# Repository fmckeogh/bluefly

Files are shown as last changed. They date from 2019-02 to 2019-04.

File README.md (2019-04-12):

# bluefly

> BLE-based light electric vehicle control system




## Building

TODO

## Components

* nRF52810 microcontrollers
* SSD1306 display
* NCR18650GA battery
* Hall-effect thumb control

## TODO

### Software

* [ ] MVP (move thumb and motor spins as a result)
* [ ] Proper BLE connection
* [ ] Display telemetry
* [ ] Transparent passthrough to VESC for configuration from PC/phone
* [ ] CLI for configuring remote/receiver
* [ ] OTA firmware updates of remote and receiver
* [ ] Battery percent on phone
* [ ] HomeKit integration

### Hardware

* [X] Finalise breadboard design of both remote and receiver
* [x] Initial PCB design and order of both remote and receiver
* [ ] Case design

## Contributing

Issues and PRs very welcome :)

## License

Mozilla Public License Version 2.0([LICENSE](LICENSE) or
  https://www.mozilla.org/en-US/MPL/2.0/)

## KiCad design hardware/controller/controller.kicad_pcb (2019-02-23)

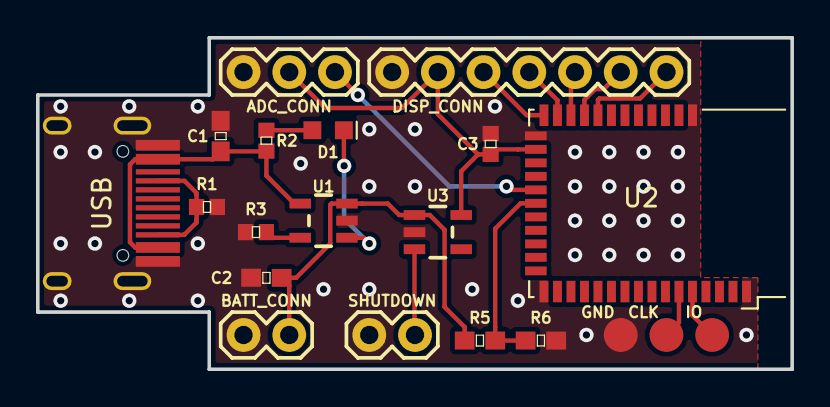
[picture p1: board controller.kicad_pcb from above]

Board: 2 copper layers, 41.9 x 18.4 mm, 20 parts (0 on the bottom side), 18 nets.

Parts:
C1, C2: 4.7UF; 0603
C3: 1.0UF-0402-16V-10%; 0402
D1: LED-BLUE0603; LED-0603
J1: ADC_CONN; 1X03
J2: DISP_CONN; 1X07
J3: BATT_CONN; 1X02
J4: SHUTDOWN; 1X02
R1: 5.1K; 0402
R2: RESISTOR0402; 0402
R3: 2K; 0402
R5, R6: 1MOHM-0603-1_4W-5%; 0603
SWD_CLK1: CLK; PAD.03X.05
SWD_GND1: GND; PAD.03X.05
SWD_IO1: IO; PAD.03X.05
U1: MCP73831; SOT23-5
U2: BL652; Laird_BL652
U3: TC1014; SOT23-5
USB: HRO-TYPE-C-31-M-12; HRO-TYPE-C-31-M-12-HandSoldering_modified

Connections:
/AIN0: J1.3, U2.23
/AIN1: R5.2, R6.1, U2.22
/CC: R1.1, USB.4, USB.10
/CS: J2.7, U2.32
/DC: J2.5, U2.30
/MOSI: J2.3, U2.28
/RST: J2.6, U2.31
/SCK: J2.4, U2.29
/SWDCLK: SWD_CLK1.P$1, U2.6
/SWDIO: SWD_IO1.P$1, U2.5
GND: C1.2, C2.2, C3.2, J1.1, J2.1, J3.1, J4.2, R1.2, R3.2, R6.2, SWD_GND1.P$1, U1.2, U2.1, U2.16, U2.27, U2.39, U3.2, USB.1, USB.12, USB.13
unnamed: D1.A, R2.1
unnamed: D1.C, U1.1
unnamed: J4.1, U3.3
unnamed: R3.1, U1.5
VCC: C3.1, J1.2, J2.2, U2.26, U3.5
V_BATT: C2.1, J3.2, R5.1, U1.3, U3.1
V_USB: C1.1, R2.2, U1.4, USB.2, USB.11

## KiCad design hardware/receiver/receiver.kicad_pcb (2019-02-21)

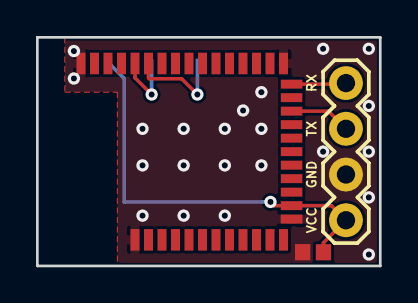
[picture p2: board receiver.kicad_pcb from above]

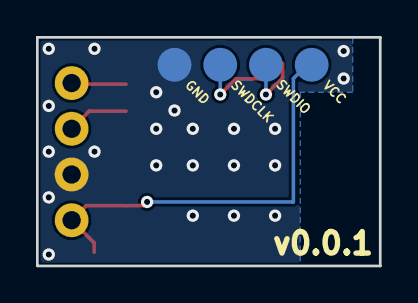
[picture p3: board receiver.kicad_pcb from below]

Board: 2 copper layers, 19.0 x 12.7 mm, 5 parts (4 on the bottom side), 2 nets.

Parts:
C1: 0.1UF-0402-16V-10%; 0402_mod
GND1: TEST-POINT3; PAD.03X.05
SWDCLK1: TEST-POINT3; PAD.03X.05
SWDIO1: TEST-POINT3; PAD.03X.05
VCC1: TEST-POINT3; PAD.03X.05

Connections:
GND: C1.2, GND1.P$1
VCC: C1.1, VCC1.P$1

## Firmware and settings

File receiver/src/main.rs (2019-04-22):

#![no_std]
#![no_main]

// We need to import this crate explicitly so we have a panic handler
extern crate panic_semihosting;

mod logger;
mod radio;
mod timer;

use {
    crate::logger::{BbqLogger, StampedLogger},
    crate::{
        radio::{BleRadio, PacketBuffer},
        timer::{BleTimer, StampSource},
    },
    bbqueue::{bbq, BBQueue, Consumer},
    core::fmt::Write,
    log::{info, LevelFilter},
    nrf52810_hal::{
        self as hal,
        gpio::Level,
        nrf52810_pac::{self as pac, UARTE0},
        prelude::*,
        uarte::{Baudrate, Parity, Uarte},
    },
    rtfm::app,
    rubble::{
        beacon::{BeaconScanner, ScanCallback},
        gatt::GattServer,
        l2cap::{BleChannelMap, L2CAPState},
        link::{
            ad_structure::AdStructure, filter::WhitelistFilter, queue, AddressKind, DeviceAddress,
            HardwareInterface, LinkLayer, Responder, MAX_PDU_SIZE,
        },
        security_manager::NoSecurity,
        time::{Duration, Timer},
    },
};

type Logger = StampedLogger<StampSource<pac::TIMER0>, BbqLogger>;

/// Hardware interface for the BLE stack (nRF52810 implementation).
pub struct HwNRf52810 {}

impl HardwareInterface for HwNRf52810 {
    type Timer = BleTimer<pac::TIMER0>;
    type Tx = BleRadio;
}

/// Whether to broadcast a beacon or to establish a proper connection.
///
/// This is just used to test different code paths. Note that you can't do both
/// at the same time unless you also generate separate device addresses.
const TEST_BEACON: bool = false;

/// Stores the global logger used by the `log` crate.
static mut LOGGER: Option<logger::WriteLogger<Logger>> = None;

#[app(device = nrf52810_hal::nrf52810_pac)]
const APP: () = {
    static mut BLE_TX_BUF: PacketBuffer = [0; MAX_PDU_SIZE];
    static mut BLE_RX_BUF: PacketBuffer = [0; MAX_PDU_SIZE];
    static mut BLE_LL: LinkLayer<HwNRf52810> = ();
    static mut BLE_R: Responder<BleChannelMap<GattServer<'static>, NoSecurity>> = ();
    static mut RADIO: BleRadio = ();
    static mut SCANNER: rubble::beacon::BeaconScanner<
        PwmCallback,
        rubble::link::filter::WhitelistFilter<core::iter::Once<rubble::link::DeviceAddress>>,
    > = ();
    static mut SERIAL: Uarte<UARTE0> = ();
    static mut LOG_SINK: Consumer = ();

    #[init(resources = [BLE_TX_BUF, BLE_RX_BUF])]
    fn init() {
        {
            // On reset the internal high frequency clock is used, but starting the HFCLK task
            // switches to the external crystal; this is needed for Bluetooth to work.

            device
                .CLOCK
                .tasks_hfclkstart
                .write(|w| unsafe { w.bits(1) });
            while device.CLOCK.events_hfclkstarted.read().bits() == 0 {}
        }

        let ble_timer = BleTimer::init(device.TIMER0);

        let p0 = device.P0.split();

        let mut serial = {
            let rxd = p0.p0_08.into_floating_input().degrade();
            let txd = p0.p0_06.into_push_pull_output(Level::Low).degrade();

            let pins = hal::uarte::Pins {
                rxd,
                txd,
                cts: None,
                rts: None,
            };

            device
                .UARTE0
                .constrain(pins, Parity::EXCLUDED, Baudrate::BAUD1M)
        };
        writeln!(serial, "\n--- INIT ---").unwrap();

        let device_address = DeviceAddress::new([0, 0, 0, 0, 0, 0], AddressKind::Random);

        let mut radio = BleRadio::new(device.RADIO, resources.BLE_TX_BUF, resources.BLE_RX_BUF);

        let log_stamper = ble_timer.create_stamp_source();
        let (tx, log_sink) = bbq![10000].unwrap().split();
        let logger = StampedLogger::new(BbqLogger::new(tx), log_stamper);

        let log = logger::WriteLogger::new(logger);
        // Safe, since we're the only thread and interrupts are off
        unsafe {
            LOGGER = Some(log);
            log::set_logger(LOGGER.as_ref().unwrap()).unwrap();
        }
        log::set_max_level(LevelFilter::max());

        info!("READY");

        // Create TX/RX queues
        let (tx, tx_cons) = queue::create(bbq![1024].unwrap());
        let (rx_prod, rx) = queue::create(bbq![1024].unwrap());

        // Create the actual BLE stack objects
        let mut ll = LinkLayer::<HwNRf52810>::new(device_address, ble_timer);

        let resp = Responder::new(
            tx,
            rx,
            L2CAPState::new(BleChannelMap::with_attributes(GattServer::new())),
        );

        if !TEST_BEACON {
            // Send advertisement and set up regular interrupt
            let next_update = ll
                .start_advertise(
                    Duration::from_millis(200),
                    &[AdStructure::CompleteLocalName("CONCVRRENS CERTA CELERIS")],
                    &mut radio,
                    tx_cons,
                    rx_prod,
                )
                .unwrap();
            ll.timer().configure_interrupt(next_update);
        }

        let scanner = {
            let filter = WhitelistFilter::from_address(DeviceAddress::new(
                [169, 255, 235, 206, 50, 121],
                AddressKind::Random,
            ));

            let callback = {
                device.PWM0.psel.out[0]
                    .write(|w| unsafe { w.pin().bits(0x08).connect().connected() });
                device.PWM0.enable.write(|w| w.enable().enabled());
                device.PWM0.mode.write(|w| w.updown().up());
                device.PWM0.prescaler.write(|w| w.prescaler().div_32());
                device
                    .PWM0
                    .countertop
                    .write(|w| unsafe { w.countertop().bits(8_000) }); // 20ms at div_32
                device.PWM0.loop_.write(|w| w.cnt().disabled());
                device
                    .PWM0
                    .decoder
                    .write(|w| w.load().common().mode().next_step());
                device.PWM0.seq0.refresh.write(|w| w.cnt().continuous());
                device
                    .PWM0
                    .seq0
                    .enddelay
                    .write(|w| unsafe { w.cnt().bits(0) });
                let mut val: u16 = 7220;
                device.PWM0.seq0.cnt.write(|w| unsafe { w.cnt().bits(1) });
                device
                    .PWM0
                    .seq0
                    .ptr
                    .write(|w| unsafe { w.ptr().bits(((&mut val) as *mut _) as u32) });

                device.PWM0.tasks_seqstart[0].write(|w| w.tasks_seqstart().trigger());
                device
                    .PWM0
                    .tasks_nextstep
                    .write(|w| w.tasks_nextstep().trigger());

                PwmCallback(device.PWM0)
            };

            BeaconScanner::with_filter(callback, filter)
        };

        RADIO = radio;
        BLE_LL = ll;
        BLE_R = resp;
        SCANNER = scanner;
        SERIAL = serial;
        LOG_SINK = log_sink;
    }

    #[interrupt(resources = [RADIO, BLE_LL, SCANNER])]
    fn RADIO() {
        let next_update = resources
            .RADIO
            .recv_interrupt(resources.BLE_LL.timer().now(), &mut resources.SCANNER);

        //let cmd = resources.SCANNER.process_adv_packet()
        resources.BLE_LL.timer().configure_interrupt(next_update);
    }

    #[interrupt(resources = [RADIO, BLE_LL, SCANNER])]
    fn TIMER0() {
        let timer = resources.BLE_LL.timer();
        if !timer.is_interrupt_pending() {
            return;
        }
        timer.clear_interrupt();

        let cmd = resources.BLE_LL.update(&mut *resources.RADIO);
        resources.RADIO.configure_receiver(cmd.radio);

        resources
            .BLE_LL
            .timer()
            .configure_interrupt(cmd.next_update);
    }

    #[idle(resources = [LOG_SINK, SERIAL, BLE_R])]
    fn idle() -> ! {
        // Drain the logging buffer through the serial connection
        loop {
            while let Ok(grant) = resources.LOG_SINK.read() {
                for chunk in grant.buf().chunks(255) {
                    resources.SERIAL.write(chunk).unwrap();
                }

                resources.LOG_SINK.release(grant.buf().len(), grant);
            }

            if resources.BLE_R.has_work() {
                resources.BLE_R.process_one().unwrap();
            }
        }
    }
};

pub struct PwmCallback(pac::PWM0);

impl ScanCallback for PwmCallback {
    fn beacon<'a, I>(&mut self, _adv_addr: DeviceAddress, adv_data: I)
    where
        I: Iterator<Item = AdStructure<'a>>,
    {
        match adv_data.last() {
            Some(AdStructure::Unknown { ty: _, data }) => {
                info!("got val: {}", data[0]);

                let mut val: u16 = 6990 + (u16::from(data[0]) * 2);
                self.0.seq0.cnt.write(|w| unsafe { w.cnt().bits(1) });
                self.0
                    .seq0
                    .ptr
                    .write(|w| unsafe { w.ptr().bits(((&mut val) as *mut _) as u32) });

                self.0.tasks_seqstart[0].write(|w| w.tasks_seqstart().trigger());
                self.0
                    .tasks_nextstep
                    .write(|w| w.tasks_nextstep().trigger());
            }
            _ => (),
        }
    }
}

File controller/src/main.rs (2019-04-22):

#![no_std]
#![no_main]
#![feature(alloc)]
#![feature(global_allocator)]
#![feature(lang_items)]

// We need to import this crate explicitly so we have a panic handler
#[macro_use]
extern crate alloc;
extern crate alloc_cortex_m;
extern crate panic_semihosting;
#[macro_use]
extern crate cortex_m_rt as rt;

mod logger;

use {
    crate::logger::{BbqLogger, StampedLogger},
    alloc_cortex_m::CortexMHeap,
    bbqueue::{bbq, BBQueue, Consumer},
    core::alloc::Layout,
    core::fmt::Write,
    embedded_graphics::{fonts::Font12x16, image::Image1BPP, prelude::*},
    embedded_hal::adc::OneShot,
    log::{info, LevelFilter},
    nrf52810_hal::{
        self as hal,
        gpio::{
            p0::{P0_02, P0_03},
            Floating, Input, Level, Output, Pin, PushPull,
        },
        nrf52810_pac::{self as pac, SPIM0, UARTE0},
        prelude::*,
        saadc::{Gain, Oversample, Reference, Resistor, Resolution, Saadc, SaadcConfig, Time},
        spim::{self, Frequency, Spim, MODE_0},
        uarte::{Baudrate, Parity, Uarte},
    },
    rtfm::app,
    rubble::{
        beacon::Beacon,
        gatt::GattServer,
        l2cap::{BleChannelMap, L2CAPState},
        link::{
            ad_structure::AdStructure, queue, AddressKind, DeviceAddress, HardwareInterface,
            LinkLayer, Responder, MAX_PDU_SIZE,
        },
        security_manager::NoSecurity,
        time::Timer,
    },
    rubble_nrf52810::{
        radio::{BleRadio, PacketBuffer},
        timer::{BleTimer, StampSource},
    },
    ssd1306::{
        displayrotation::DisplayRotation, interface::spi::SpiInterface,
        mode::graphics::GraphicsMode, prelude::*,
    },
};

#[global_allocator]
static ALLOCATOR: CortexMHeap = CortexMHeap::empty();

type Logger = StampedLogger<StampSource<pac::TIMER0>, BbqLogger>;

/// Hardware interface for the BLE stack (nRF52810 implementation).
pub struct HwNRf52810 {}

impl HardwareInterface for HwNRf52810 {
    type Timer = BleTimer<pac::TIMER0>;
    type Tx = BleRadio;
}

/// Stores the global logger used by the `log` crate.
static mut LOGGER: Option<logger::WriteLogger<Logger>> = None;

#[app(device = nrf52810_hal::nrf52810_pac)]
const APP: () = {
    static mut BLE_TX_BUF: PacketBuffer = [0; MAX_PDU_SIZE];
    static mut BLE_RX_BUF: PacketBuffer = [0; MAX_PDU_SIZE];
    static mut BLE_LL: LinkLayer<HwNRf52810> = ();
    static mut BLE_R: Responder<BleChannelMap<GattServer<'static>, NoSecurity>> = ();
    static mut RADIO: BleRadio = ();
    static mut BEACON_TIMER: pac::TIMER1 = ();
    static mut SERIAL: Uarte<UARTE0> = ();
    static mut LOG_SINK: Consumer = ();

    static mut DISPLAY: GraphicsMode<SpiInterface<Spim<SPIM0>, Pin<Output<PushPull>>>> = ();

    static mut ADC: Saadc = ();
    static mut ADC_CONTROL_PIN: P0_02<Input<Floating>> = ();
    static mut ADC_BATT_PIN: P0_03<Input<Floating>> = ();

    #[init(resources = [BLE_TX_BUF, BLE_RX_BUF])]
    fn init() {
        //hprintln!("\n<< INIT >>\n").ok();
        {
            let start = rt::heap_start() as usize;
            let size = 1024; // in bytes
            unsafe { ALLOCATOR.init(start, size) }
        }

        {
            // On reset the internal high frequency clock is used, but starting the HFCLK task
            // switches to the external crystal; this is needed for Bluetooth to work.

            device
                .CLOCK
                .tasks_hfclkstart
                .write(|w| unsafe { w.bits(1) });
            while device.CLOCK.events_hfclkstarted.read().bits() == 0 {}
        }

        let ble_timer = BleTimer::init(device.TIMER0);

        {
            // Configure TIMER1 as the beacon timer. It's only used as a 16-bit timer.
            let timer = &mut device.TIMER1;
            timer.bitmode.write(|w| w.bitmode()._16bit());
            // prescaler = 2^9    = 512
            // 16 MHz / prescaler = 31_250 Hz
            timer.prescaler.write(|w| unsafe { w.prescaler().bits(9) }); // 0-9
            timer.intenset.write(|w| w.compare0().set());
            timer.shorts.write(|w| w.compare0_clear().enabled());
            timer.cc[0].write(|w| unsafe { w.bits(31_250 / 50) }); // ~50x per second
            timer.tasks_clear.write(|w| unsafe { w.bits(1) });

            timer.tasks_start.write(|w| unsafe { w.bits(1) });
        }

        let p0 = device.P0.split();

        let mut serial = {
            let rxd = p0.p0_08.into_floating_input().degrade();
            let txd = p0.p0_31.into_push_pull_output(Level::Low).degrade();

            let pins = hal::uarte::Pins {
                rxd,
                txd,
                cts: None,
                rts: None,
            };

            device
                .UARTE0
                .constrain(pins, Parity::EXCLUDED, Baudrate::BAUD1M)
        };
        writeln!(serial, "\n--- INIT ---").unwrap();

        let radio = BleRadio::new(device.RADIO, resources.BLE_TX_BUF, resources.BLE_RX_BUF);

        let log_stamper = ble_timer.create_stamp_source();
        let (tx, log_sink) = bbq![10000].unwrap().split();
        let logger = StampedLogger::new(BbqLogger::new(tx), log_stamper);

        let log = logger::WriteLogger::new(logger);
        // Safe, since we're the only thread and interrupts are off
        unsafe {
            LOGGER = Some(log);
            log::set_logger(LOGGER.as_ref().unwrap()).unwrap();
        }
        log::set_max_level(LevelFilter::max());

        info!("READY");

        // Create TX/RX queues
        let (tx, _tx_cons) = queue::create(bbq![1024].unwrap());
        let (_rx_prod, rx) = queue::create(bbq![1024].unwrap());

        // Create the actual BLE stack objects
        let ll = LinkLayer::<HwNRf52810>::new(
            DeviceAddress::new([169, 255, 235, 206, 50, 121], AddressKind::Random),
            ble_timer,
        );

        let resp = Responder::new(
            tx,
            rx,
            L2CAPState::new(BleChannelMap::with_attributes(GattServer::new())),
        );

        let adc = {
            let config = SaadcConfig {
                resolution: Resolution::_14BIT,
                oversample: Oversample::OVER256X,
                reference: Reference::VDD1_4,
                gain: Gain::GAIN1_4,
                resistor: Resistor::BYPASS,
                time: Time::_40US,
            };

            Saadc::new(device.SAADC, config)
        };

        let display = {
            let spi = {
                let mosi = Some(p0.p0_15.into_push_pull_output(Level::Low).degrade());
                let sck = p0.p0_13.into_push_pull_output(Level::Low).degrade();

                Spim::new(
                    device.SPIM0,
                    spim::Pins {
                        sck,
                        mosi,
                        miso: None,
                    },
                    Frequency::M8,
                    MODE_0,
                    0u8,
                )
            };
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

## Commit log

2018-05-06 Switch to known-good nightly
2018-05-12 Broken, SPI display
2018-05-12 SPI display working
2018-05-13 Started work on battery icon, embedded-icons crate?
2018-05-13 Added remote battery icon
2018-05-13 Working on external interrupt
2018-05-14 Forgot to stage .travis.yml
2018-05-14 Interrupt still not working :(
    [main.rs]
2018-07-23 Empty hardware projects
    [mremote.FCStd, mremote.kicad_pcb, mremote.sch]
2018-07-24 Change to 433MHz to match antennae
2018-07-24 Initial case design
    [mremote.FCStd]
2018-07-25 New case design
    [mremote.FCStd]
2018-07-25 Added sensor, display and USB to case
    [mremote.FCStd]
2018-08-12 Started ugly case design
    [mremote.FCStd]
2018-08-12 Started PCB design
2019-02-10 remove radios and add adc
2019-02-11 Bump vesc-comm from 0.1.0 to 0.1.1
    Bumps [vesc-comm](https://github.com/chocol4te/vesc-comm) from 0.1.0 to 0.1.1.
    - [Release notes](https://github.com/chocol4te/vesc-comm/releases)
    - [Commits](https://github.com/chocol4te/vesc-comm/commits)
2019-02-21 feat: add hardware
    [_saved_boostboard1.sch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]
2019-02-21 test: 2 stage CI
2019-02-21 fix: remove kicad deps and bad case design
    [_saved_boostboard1.sch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]
2019-02-23 feat: finish controller pcb
    [controller.kicad_pcb, controller.sch, receiver.sch]
2019-03-28 feat: ADC working
2019-03-28 chore: sensor scaling
2019-04-17 feat: potentiometer control of VESC over BLE working
2019-04-18 fix: controller ADC scaling
    [main.rs]
2019-04-19 ci: switch to beta until https://github.com/rust-lang/rust/pull/58605 is resolved
2019-04-22 feat: use display to report current throttle
